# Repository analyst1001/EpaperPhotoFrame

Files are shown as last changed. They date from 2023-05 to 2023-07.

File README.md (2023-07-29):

# E-Paper Photo Frame

## Goals
- The main goal is to display photos on a E-paper display so that it looks similar to a photo frame. The displayed photo will change periodically.
- An additional goal is to allow the device to run on a common battery power source so that it can work without plugging into wall power.

## How to use
The script stored in `Software/transform_images.py` can be used to modify images in common format (png, jpg, etc.) to binary blobs which can be copied to a FAT32 partition (formatted with block size 512) on a SD card. These blobs are read by software starting with filename "0.bin", "1.bin", and so on and displayed on the E-paper screen. When a filename "<n>.bin" for some number `n` is not found, the software starts displaying images from "0.bin" again and keeps looping like this.

## Branches
This branch has PCB design to hold all the components for E-paper photo frame with connections to external battery, external E-paper display, external LEDs, and external SD card storage. Additionally it has code that can be flashed to STM32 MCU to use the PCB as an Epaper photo frame.
The branch `development_board` has code to run software on the development board with appropriate connections to external devices.

## MCU interfaces
- SPI interface is used to communicate with SD card and E-paper display.
- UART interface is used to log debug messages. This can be disabled by a C macro to reduce power usage in the final version.
- GPIOs to power on/off BUSY and ERROR LEDs, and SD card.

## Code implementation
1. Initialize the MCU using HAL layer. Configure system clock to use 80MHz. Using the max frequency allows SPI interface to SD card to communicate with max speed. This will allow SD card to be powered on for a shorter amount of time hence reducing the power usage (given that I plan to keep the MCU in low power mode for hours).
2. Initialize LEDs and RTC peripheral. BUSY LED indicates that the MCU is busy using the SD card or the E-paper display. ERROR LED indicates that an irrecoverable error has occurred. RTC peripheral is used to leverage the WakeUp timer in order to wake up the MCU from sleep mode periodically.
3. Initialize SD card and E-paper display.
4. Read data from the file to display and send it to E-paper display. Refresh the display and put it to sleep when the image is displayed.
5. Enable WakeUp interrupt to wake up the processor after given time interval.
6. Configure peripherals to reduce current consumption and put the MCU in Standby/Shutdown mode.

## Current consumption (TBD)

## Future Plans
- Use a data logger to measure instantaneous current consumption value with better resolution.
- Re-write the logic to use interrupt based processing. The SPI based communication can use interrupt based processing where the MCU can be put into low-power sleep mode when waiting for data transmission/reception. Same can be used when waiting for BUSY signal from E-paper display and time delays in the logic.
- Use DMA peripheral to transmit/receive large data blobs (image pixel data). STM32L4 series processor support a feature called Batch Acquisition sub-mode(BAM), as mentioned in Section 2.1.1 of [AN4621](https://www.st.com/resource/en/application_note/an4621-stm32l4-and-stm32l4-ultralowpower-features-overview-stmicroelectronics.pdf), that could allow this.

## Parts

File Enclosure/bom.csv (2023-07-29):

Item | Quantity | URL | Comments
Enclosure front cover | 1 | https://github.com/analyst1001/EpaperPhotoFrame/tree/main/Enclosure
Enclosure back cover | 1 | https://github.com/analyst1001/EpaperPhotoFrame/tree/main/Enclosure
Enclosure hanging attachment (optional) | 1 | https://github.com/analyst1001/EpaperPhotoFrame/tree/main/Enclosure
PCB | 1 | https://github.com/analyst1001/EpaperPhotoFrame/tree/main/PCB | BOM for PCB should be present in PCB directory
7.3inch ACeP 7-Color E-Paper E-Ink Display Module (800×480 Pixels) | 1 | https://www.waveshare.com/product/displays/e-paper/epaper-1/7.3inch-e-paper-f.htm | Buy one with
M3 x 0.5 mm screws | 4 | https://www.mcmaster.com/91280A039/
M3 x 0.5 mm nuts | 4 | https://www.mcmaster.com/90592A085/
LiPo battery (2000mAh) | 1 | https://mou.sr/4784RWG | Lower capacity battery should also be fine
LED Red | 1 |  | Any other color to represent error state can be used
LED Blue | 1 |  | Any other color to represent busy state can be used
Wires | 4 |  | To connect LEDs to PCB. Preferrably red for positive terminals and black for negative terminals
Double sided tape or Velcro tape | 1 |  | To attach battery to back cover
Glue | 1 |  | To attach screws to back cover

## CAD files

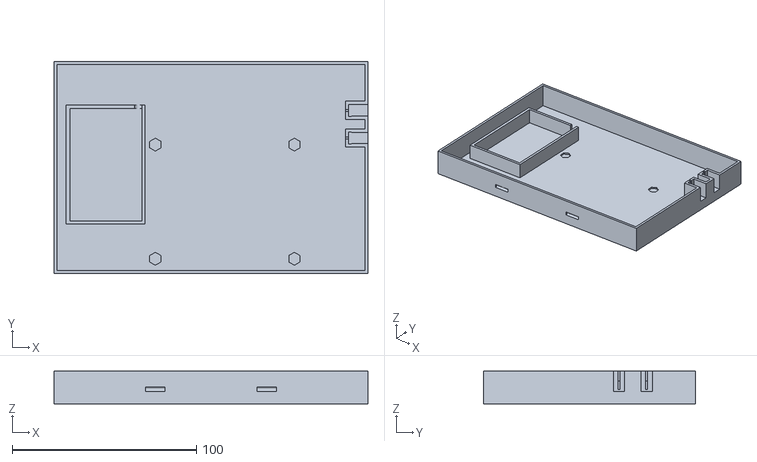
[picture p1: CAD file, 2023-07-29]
Enclosure/back_cover.stl
170.4 x 115.2 x 17.7

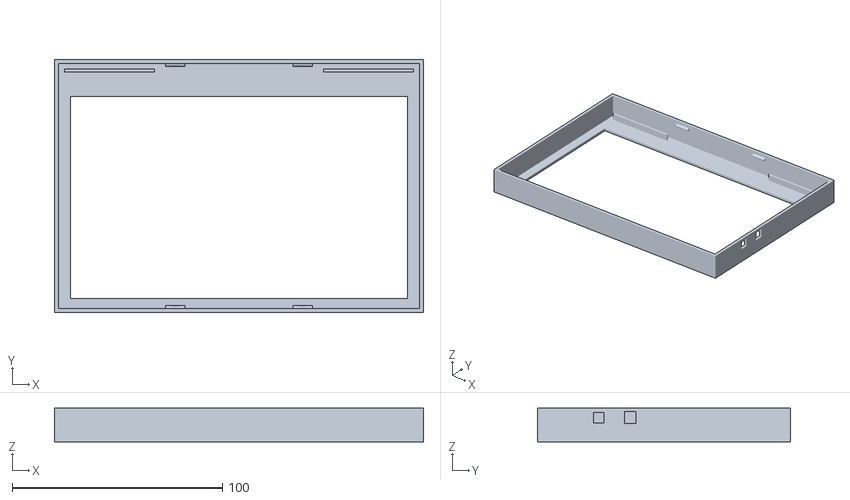
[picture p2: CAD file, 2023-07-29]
Enclosure/FrontCover_oriented.stl
175.4 x 120.2 x 16.0

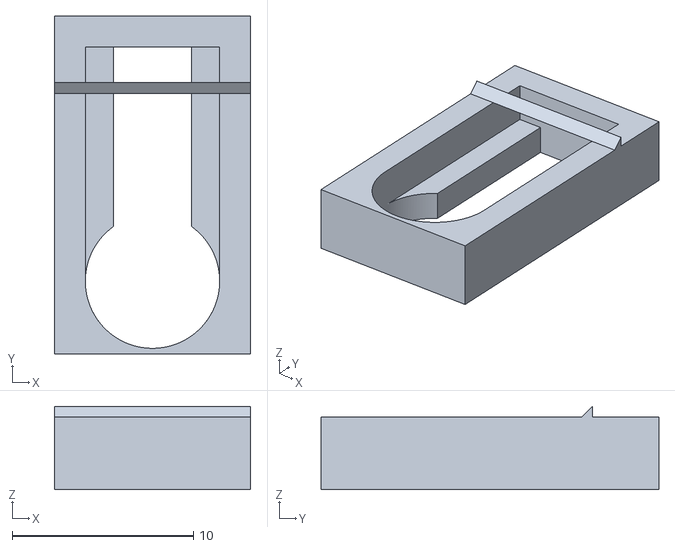
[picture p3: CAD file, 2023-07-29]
Enclosure/hanging_hook.stl
10.8 x 18.6 x 4.60

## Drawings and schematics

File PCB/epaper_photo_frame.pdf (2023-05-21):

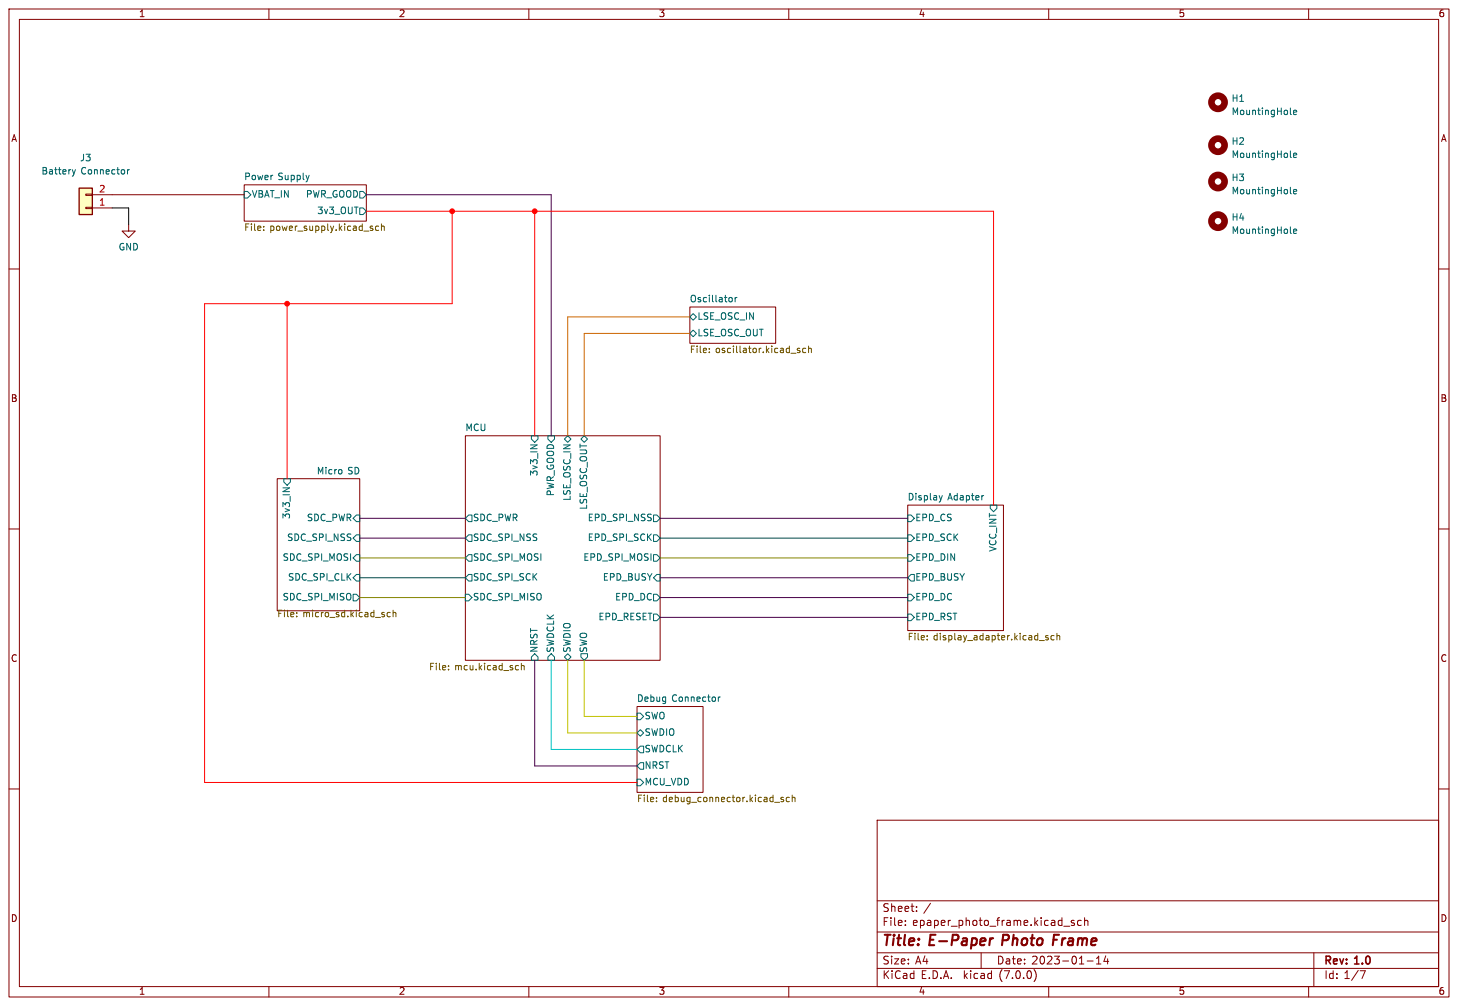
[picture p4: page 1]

LSE_OSC_OUT Oscillator File: oscillator.kicad_sch GND

SWO
SWDIO
File: epaper_photo_frame.kicad_sch Sheet: / NRST SWDCLK MCU_VDD

Id: 1/7 Title: E-Paper Photo Frame

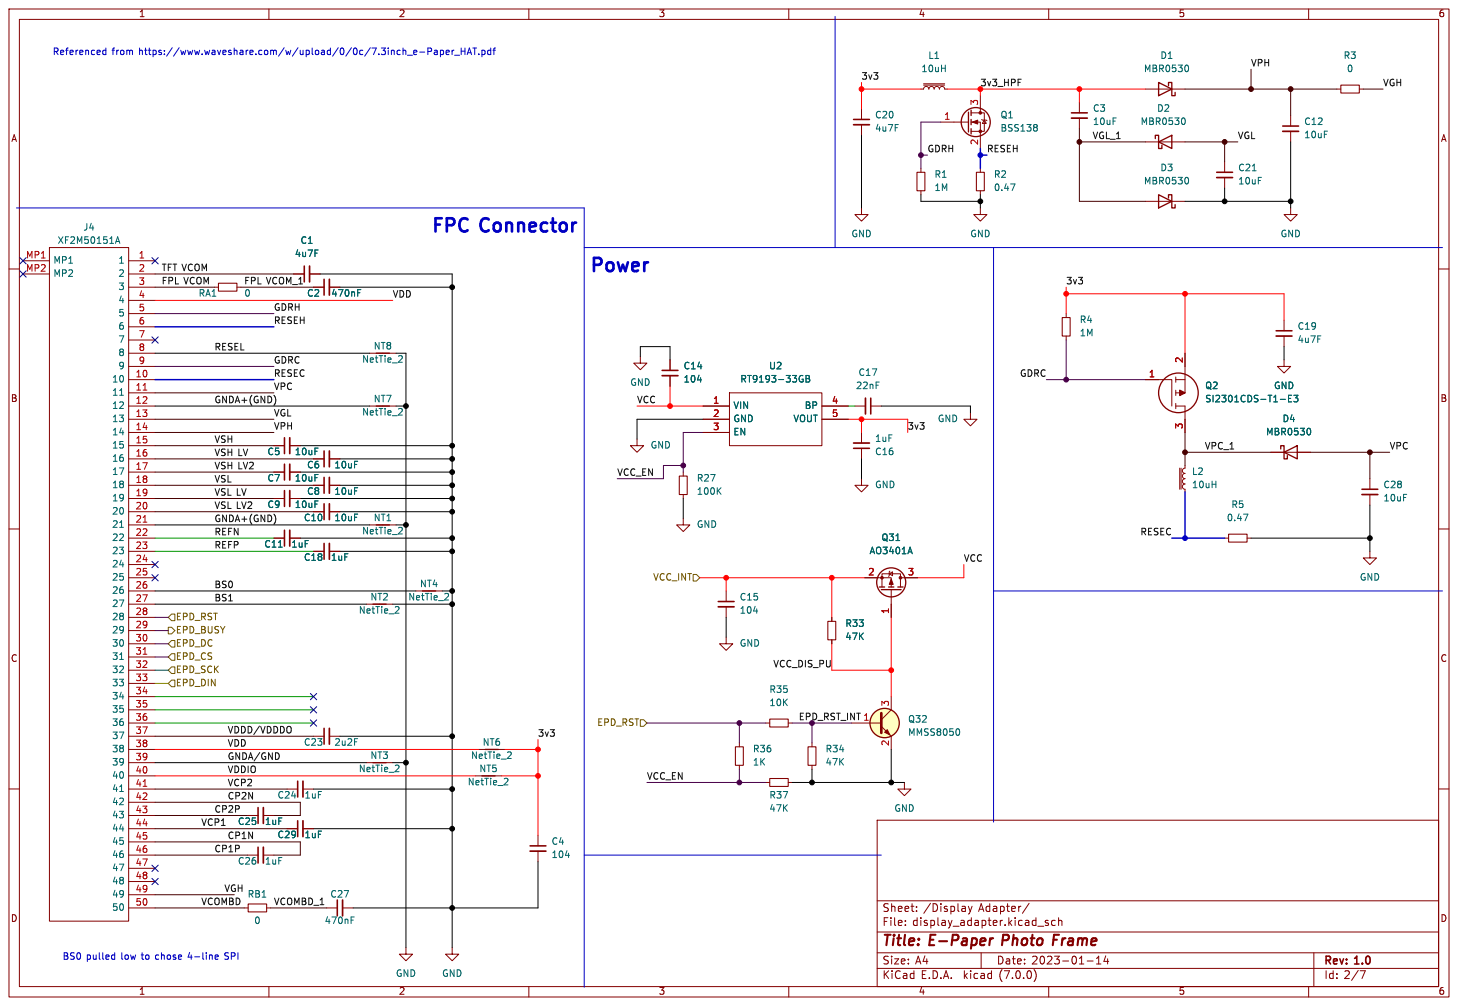
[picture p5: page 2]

Referenced from https://www.waveshare.com/w/upload/0/0c/7.3inch_e-Paper_HAT.pdf

Id: 2/7 Title: E-Paper Photo Frame

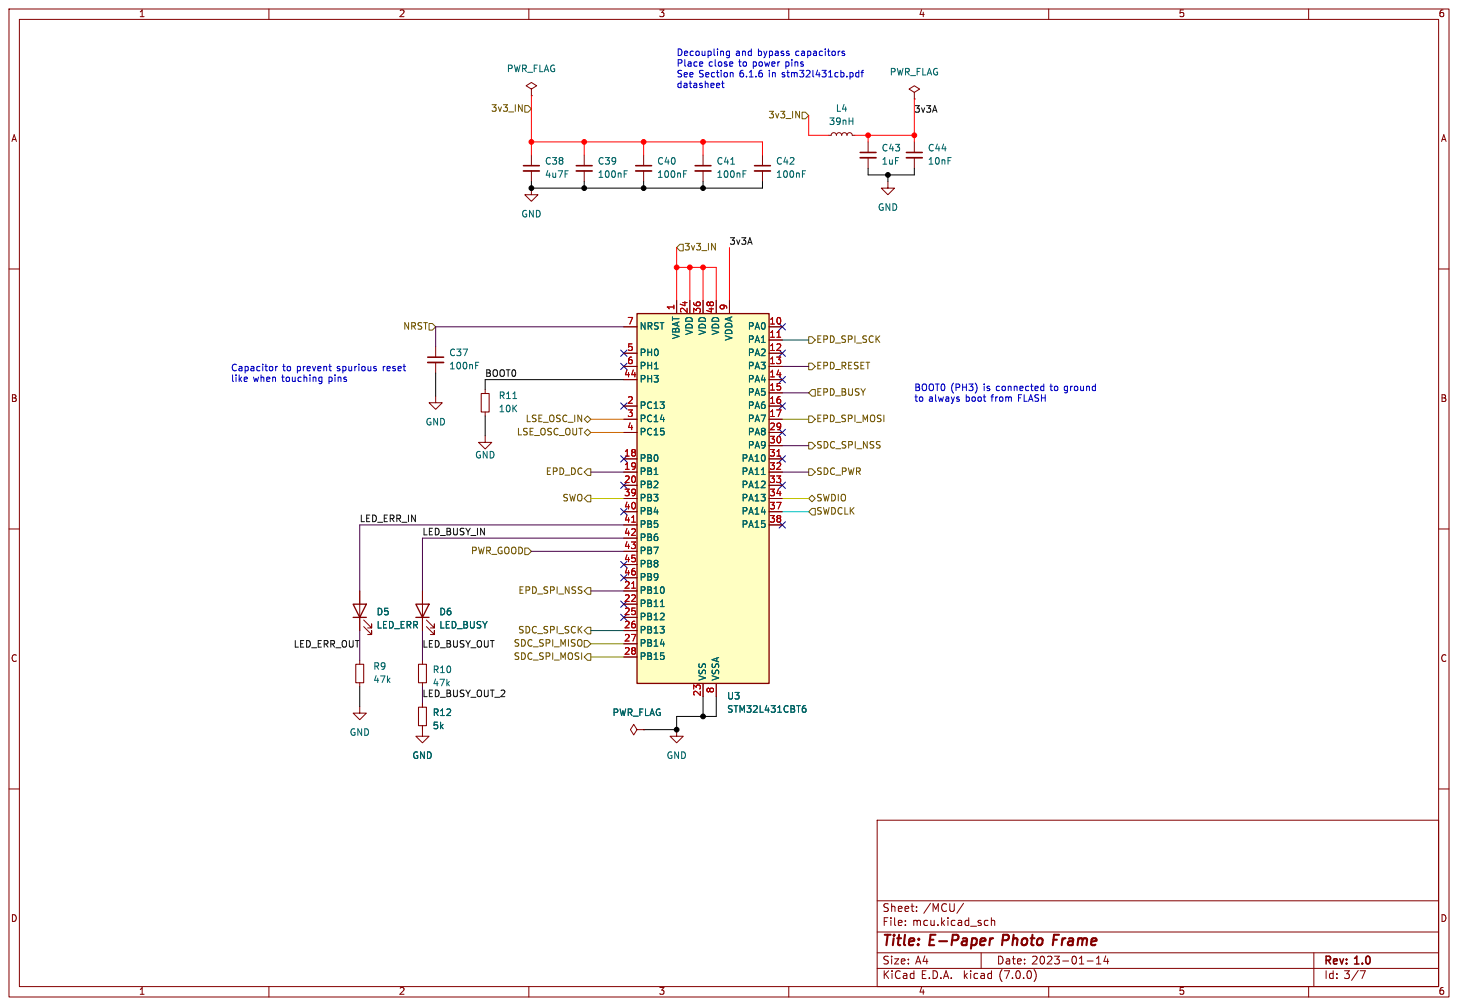
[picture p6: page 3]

1 PA0 10 PA1 11 PA2 12 PA3 13 PA4 14 PA5 15 PA6 16 PA7 17 PB0 18 PB1 19 PC13 2 PB2 20 PB10 21 PB11 22 VSS 23 VDD 24 PB12 25 PB13 26 PB14 27 PB15 28 PA8 29 PC14 3 PA9 30 PA10 31 PA11 32 PA12 33 PA13 34 VDD 36 PA14 37 PA15 38 PB3 39 PC15 4 PB4 40 PB5 41 PB6 42 PB7 43 PH3 44 PB8 45 PB9 46 VDD 48 PH0 5 PH1 6 NRST 7 VSSA
LSE_OSC_OUT EPD_SPI_NSS

Capacitor to prevent spurious reset

to always boot from FLASH

Id: 3/7 Title: E-Paper Photo Frame

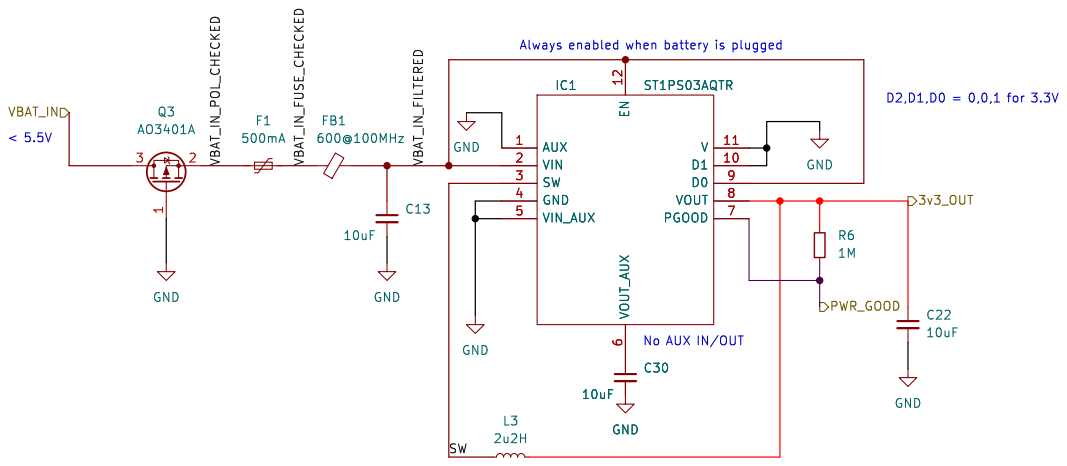
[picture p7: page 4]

File: power_supply.kicad_sch Sheet: /Power Supply/ R6

Id: 4/7 Title: E-Paper Photo Frame

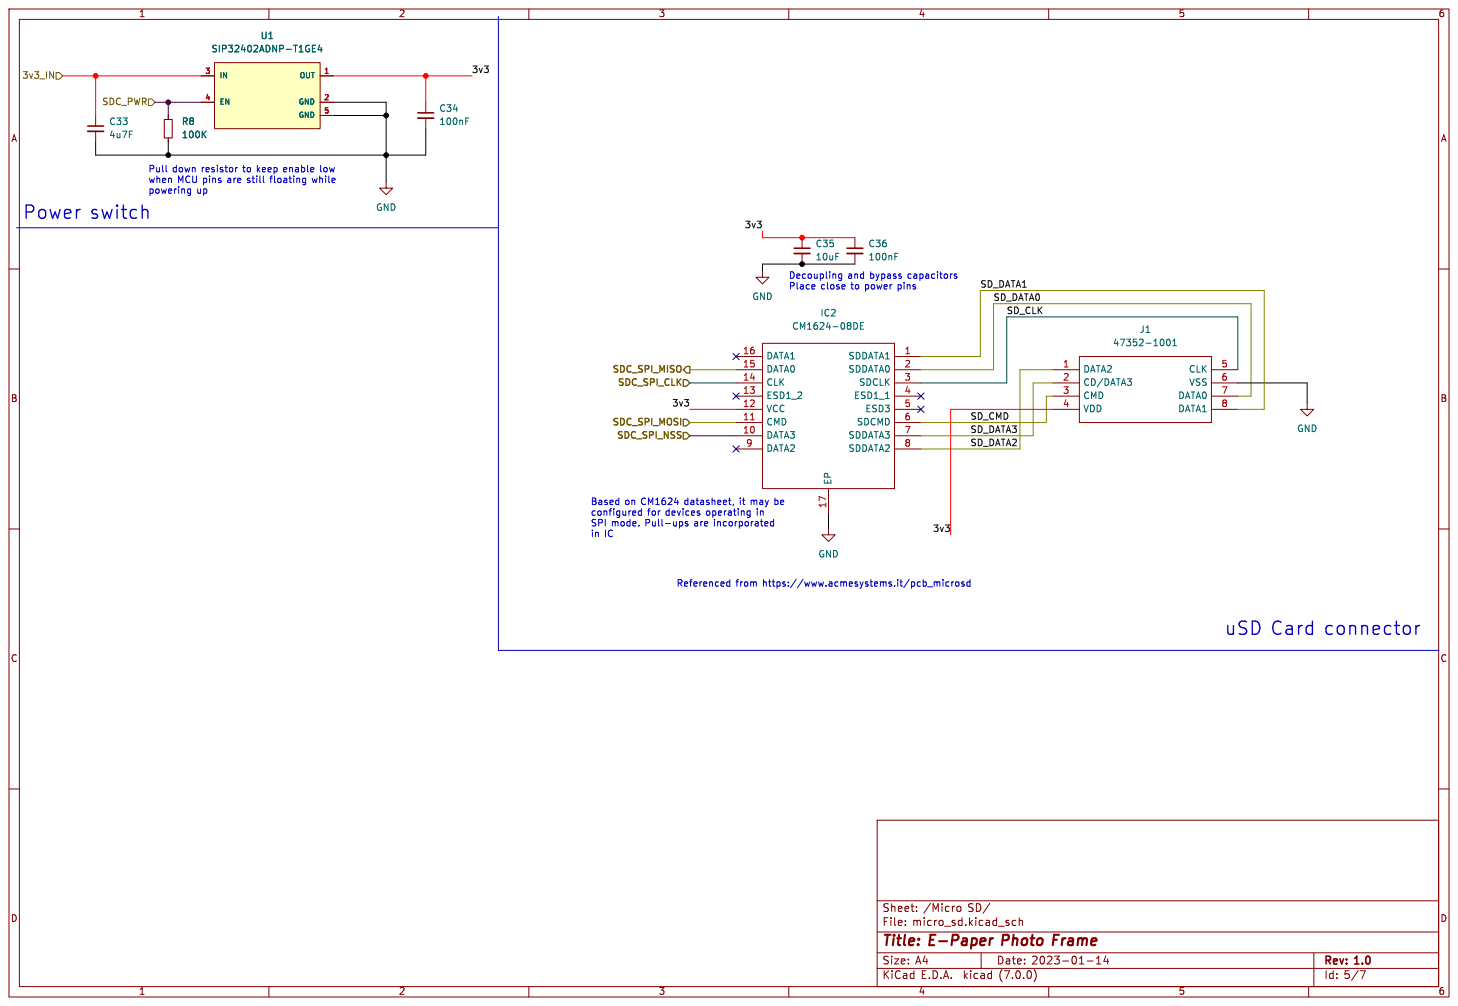
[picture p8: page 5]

Pull down resistor to keep enable low

Referenced from https://www.acmesystems.it/pcb_microsd

File: micro_sd.kicad_sch Sheet: /Micro SD/
Id: 5/7 Title: E-Paper Photo Frame

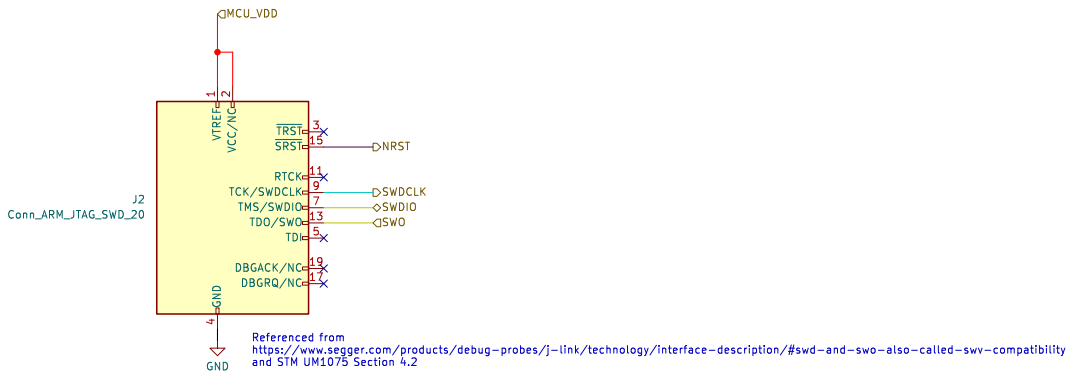
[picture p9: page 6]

1 RTCK 11 TDO/SWO 13 ~{SRST}15 DBGRQ/NC 17 DBGACK/NC 19 VCC/NC
Id: 6/7 Title: File: debug_connector.kicad_sch Sheet: /Debug Connector/ VTREF

SWDCLK NRST Referenced from

4 TDI 5 TMS/SWDIO 7 TCK/SWDCLK 9

https://www.segger.com/products/debug-probes/j-link/technology/interface-description/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 and STM UM1075 Section 4.2

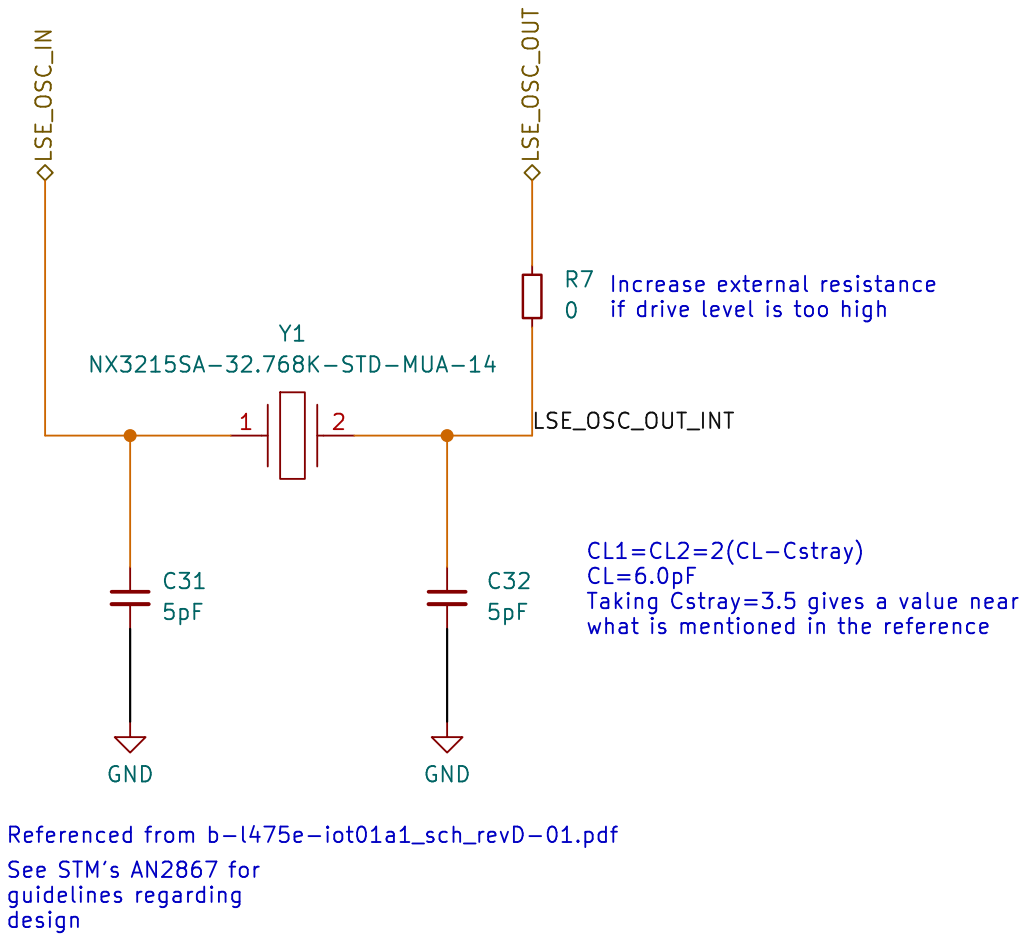
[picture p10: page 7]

Increase external resistance
if drive level is too high

Id: 7/7 Title: File: oscillator.kicad_sch Sheet: /Oscillator/

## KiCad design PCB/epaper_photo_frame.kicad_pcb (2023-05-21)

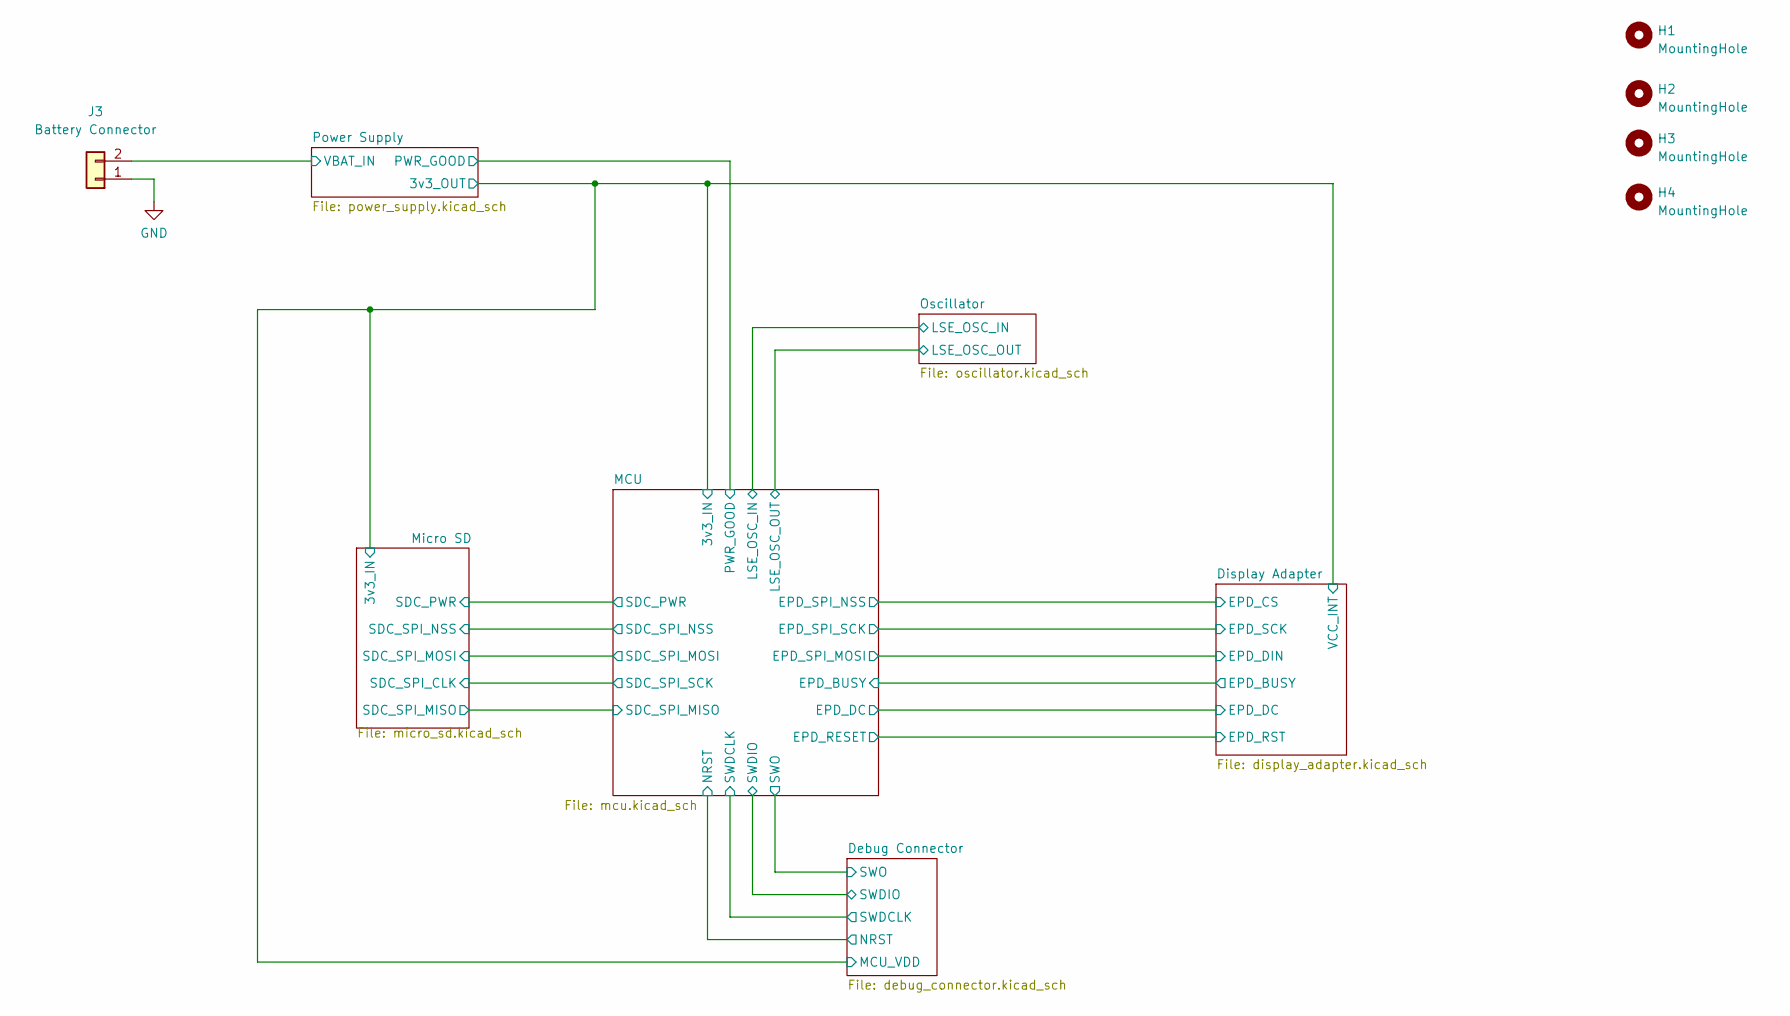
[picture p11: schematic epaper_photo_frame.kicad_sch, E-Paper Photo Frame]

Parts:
H1, H2, H3, H4: MountingHole; MountingHole_3.2mm_M3
J3: Battery Connector; JST_PH_B2B-PH-K_1x02_P2.00mm_Vertical

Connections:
/Power Supply/VBAT_IN: J3.2; also elsewhere on the board
GND: J3.1; also elsewhere on the board

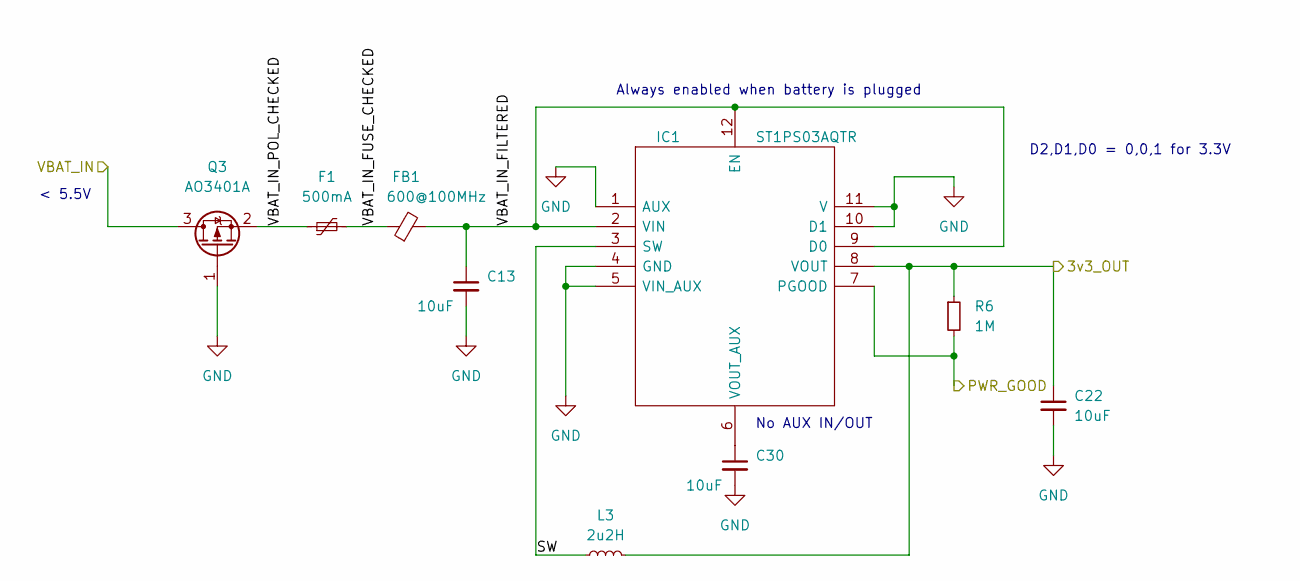
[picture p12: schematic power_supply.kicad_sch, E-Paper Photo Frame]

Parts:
C13, C22: 10uF; C_0805_2012Metric; LCSC C15850
C30: 10uF; C_0603_1608Metric; LCSC C96446
F1: 500mA; Fuse_1206_3216Metric; LCSC C69688
FB1: 600@100MHz; L_0805_2012Metric; LCSC C1017
IC1: ST1PS03AQTR; QFN40P170X200X55-12N-D; Manufacturer_Part_Number ST1PS03AQTR; Mouser Part Number 511-ST1PS03AQTR
L3: 2u2H; L_0805_2012Metric; LCSC C370034
Q3: AO3401A; SOT-23; LCSC C15127
R6: 1M; R_0805_2012Metric; LCSC C441966

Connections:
/Debug Connector/MCU_VDD: C22.1, IC1.8 (VOUT), L3.2, R6.1; also elsewhere on the board
/MCU/PWR_GOOD: IC1.7 (PGOOD), R6.2; also elsewhere on the board
/Power Supply/SW: IC1.3 (SW), L3.1
/Power Supply/VBAT_IN: Q3.3 (D); also elsewhere on the board
/Power Supply/VBAT_IN_FILTERED: C13.1, FB1.2, IC1.2 (VIN), IC1.9 (D0), IC1.12 (EN)
/Power Supply/VBAT_IN_FUSE_CHECKED: F1.2, FB1.1
/Power Supply/VBAT_IN_POL_CHECKED: F1.1, Q3.2 (S)
GND: C13.2, C22.2, C30.2, IC1.1 (AUX), IC1.4 (GND), IC1.5 (VIN_AUX), IC1.10 (D1), IC1.11 (V), Q3.1 (G); also elsewhere on the board
unnamed: C30.1, IC1.6 (VOUT_AUX)

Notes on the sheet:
D2,D1,D0 = 0,0,1 for 3.3V
No AUX IN/OUT
< 5.5V
Always enabled when battery is plugged

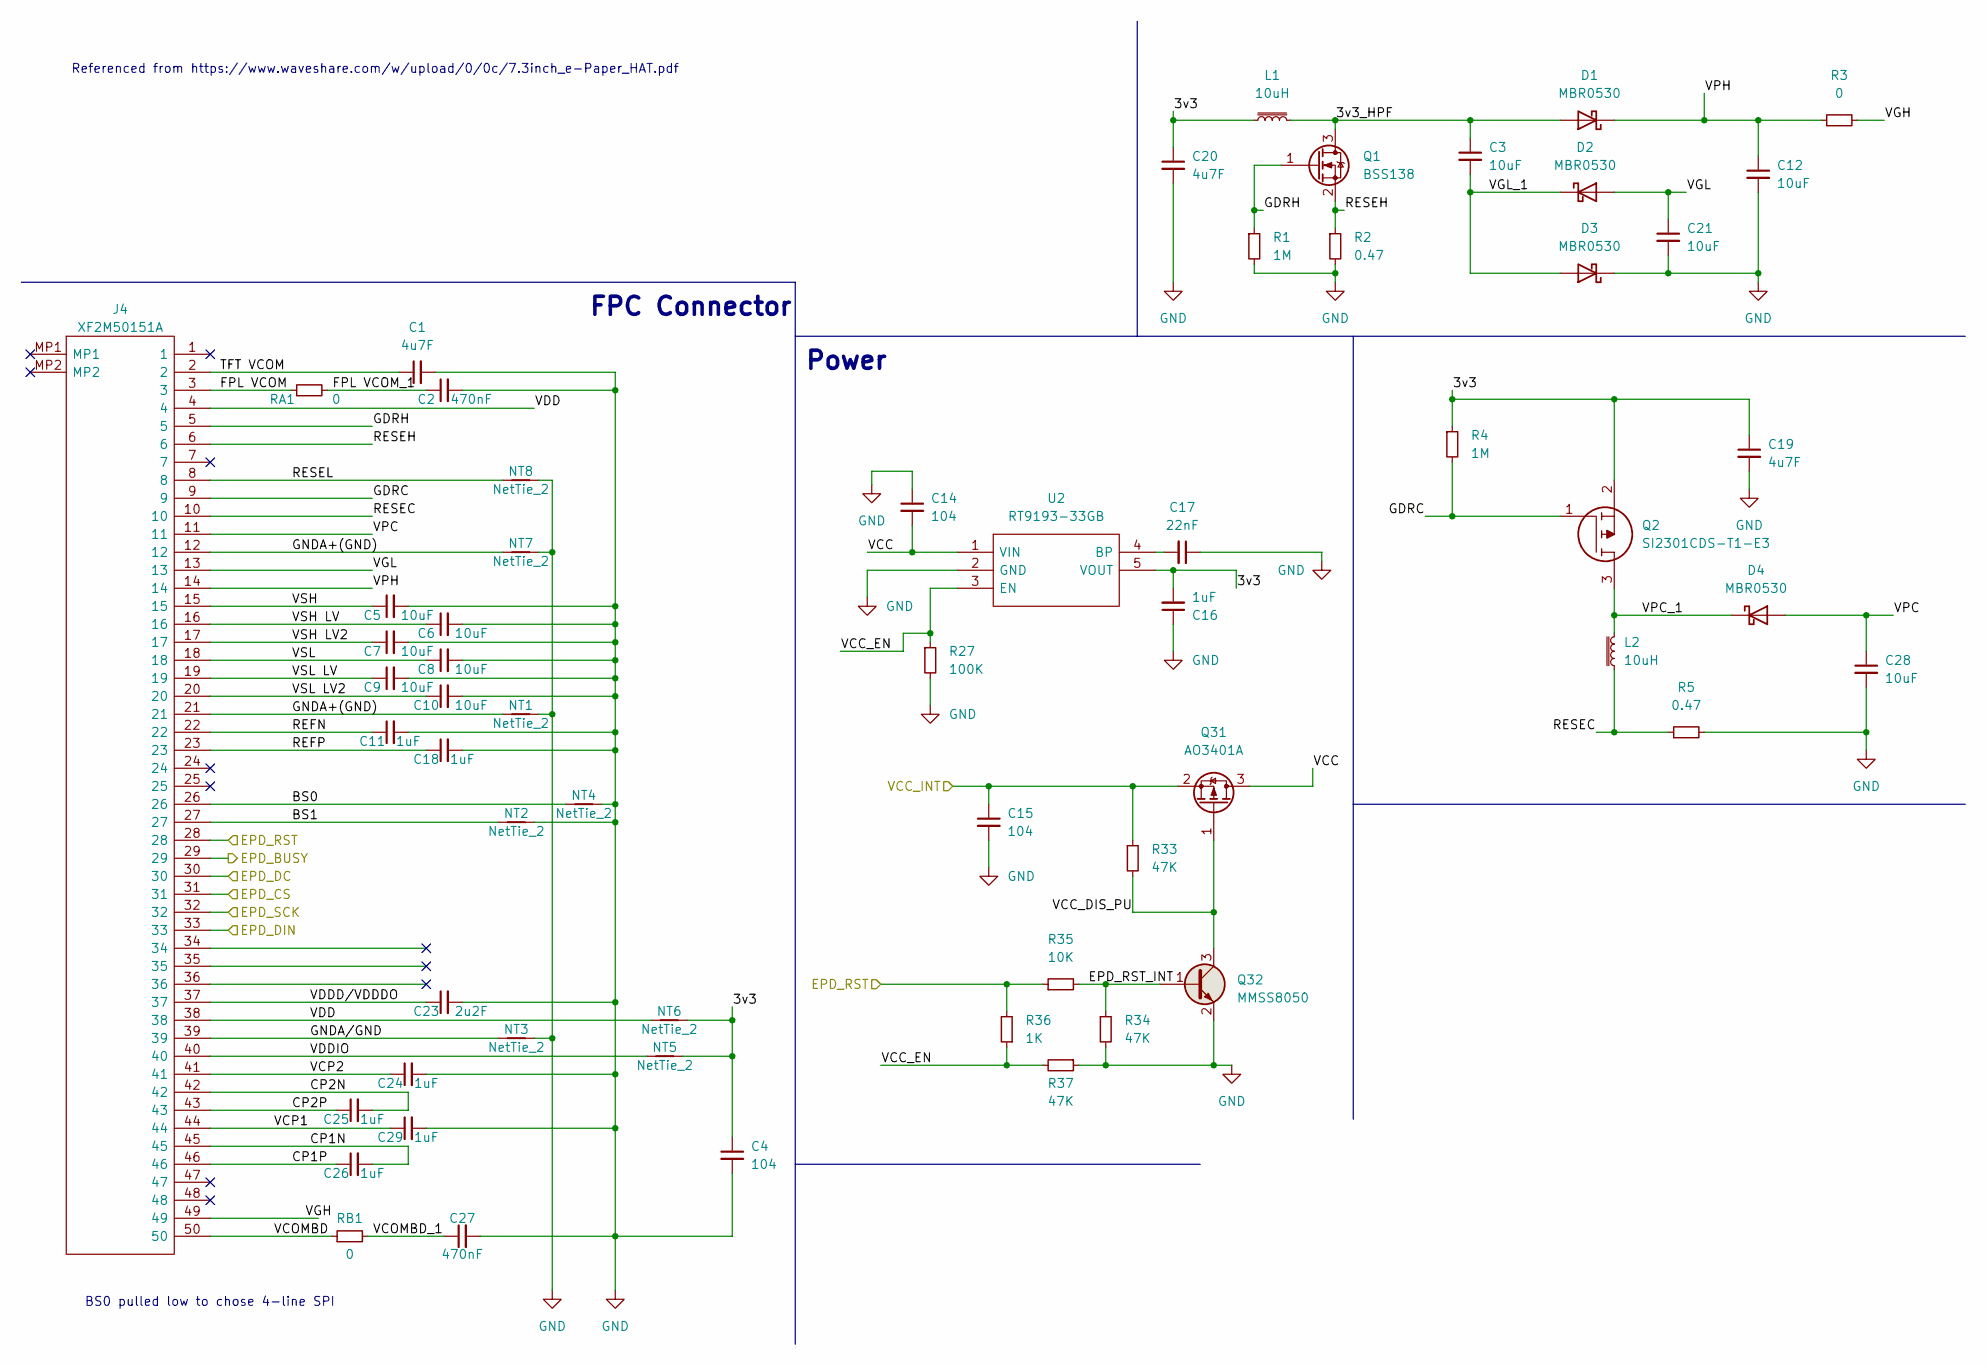
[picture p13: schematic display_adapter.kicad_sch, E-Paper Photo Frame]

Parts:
C1, C19, C20: 4u7F; C_0603_1608Metric; MAX Voltage 10V; LCSC C19666
C2, C27: 470nF; C_0603_1608Metric; MAX Voltage 25V; LCSC C1623
C3, C5, C6, C7, C8, C9, C10, C12, C21, C28: 10uF; C_0603_1608Metric; MAX Voltage 25V; LCSC C96446
C4: 104; C_0603_1608Metric; LCSC C14663
C11, C18, C24, C25, C26, C29: 1uF; C_0603_1608Metric; MAX Voltage 10V; LCSC C15849
C14, C15: 104; C_0805_2012Metric; LCSC C49678
C16: 1uF; C_0805_2012Metric; LCSC C28323
C17: 22nF; C_0805_2012Metric; LCSC C1729
C23: 2u2F; C_0603_1608Metric; MAX Voltage 6V; LCSC C23630
D1, D2, D3, D4: MBR0530; D_SOD-123; LCSC C18863
J4: XF2M50151A; Manufacturer_Part_Number XF2M50151A; LCSC C188356
L1, L2: 10uH; INDPM4040X200N; LCSC C82398
NT1, NT2, NT3, NT4, NT5, NT6, NT7, NT8: NetTie_2; NetTie-2_SMD_Pad0.5mm
Q1: BSS138; SOT-23; LCSC C82045
Q2: SI2301CDS-T1-E3; SOT95P237X112-3N; Manufacturer_Part_Number SI2301CDS-T1-E3; Mouser Part Number 781-SI2301CDS-E3
Q31: AO3401A; SOT-23; LCSC C15127
Q32: MMSS8050; SOT-23; LCSC C2150
R1, R4: 1M; R_0805_2012Metric; LCSC C441966
R2, R5: 0.47; R_0805_2012Metric; LCSC C491238
R3: 0; R_0805_2012Metric; LCSC C17477
R27: 100K; R_0805_2012Metric; LCSC C149504
R33, R34, R37: 47K; R_0805_2012Metric; LCSC C17713
R35: 10K; R_0805_2012Metric; LCSC C510098
R36: 1K; R_0805_2012Metric; LCSC C17513
RA1: 0; R_0805_2012Metric; LCSC C17477
RB1: 0; R_0805_2012Metric; LCSC C17477
U2: RT9193-33GB; SOT94P279X130-5N; Manufacturer_Part_Number RT9193-33GB; LCSC C15651

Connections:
/Debug Connector/MCU_VDD: C15.1, Q31.2 (S), R33.1; also elsewhere on the board
/Display Adapter/3v3: C4.1, C16.2, C19.1, C20.1, L1.1, NT5.2, NT6.2, Q2.2, R4.1, U2.5 (VOUT)
/Display Adapter/3v3_HPF: C3.1, D1.2 (A), L1.2, Q1.3 (D)
/Display Adapter/BS0: J4.26, NT4.1
/Display Adapter/BS1: J4.27, NT2.1
/Display Adapter/CP1N: C26.2, J4.45
/Display Adapter/CP1P: C26.1, J4.46
/Display Adapter/CP2N: C25.2, J4.42
/Display Adapter/CP2P: C25.1, J4.43
/Display Adapter/EPD_BUSY: J4.29; also elsewhere on the board
/Display Adapter/EPD_CS: J4.31; also elsewhere on the board
/Display Adapter/EPD_DC: J4.30; also elsewhere on the board
/Display Adapter/EPD_DIN: J4.33; also elsewhere on the board
/Display Adapter/EPD_RST: J4.28, R35.1, R36.2; also elsewhere on the board
/Display Adapter/EPD_RST_INT: Q32.1 (B), R34.1, R35.2
/Display Adapter/EPD_SCK: J4.32; also elsewhere on the board
/Display Adapter/FPL VCOM: J4.3, RA1.1
/Display Adapter/FPL VCOM_1: C2.1, RA1.2
/Display Adapter/GDRC: J4.9, Q2.1, R4.2
/Display Adapter/GDRH: J4.5, Q1.1 (G), R1.1
/Display Adapter/GNDA+(GND): J4.12, J4.21, NT1.1, NT7.1
/Display Adapter/GNDA/GND: J4.39, NT3.1
/Display Adapter/REFN: C11.1, J4.22
/Display Adapter/REFP: C18.1, J4.23
/Display Adapter/RESEC: J4.10, L2.1, R5.1
/Display Adapter/RESEH: J4.6, Q1.2 (S), R2.1
/Display Adapter/RESEL: J4.8, NT8.1
/Display Adapter/TFT VCOM: C1.1, J4.2
/Display Adapter/VCC: C14.2, Q31.3 (D), U2.1 (VIN)
/Display Adapter/VCC_DIS_PU: Q31.1 (G), Q32.3 (C), R33.2
/Display Adapter/VCC_EN: R27.1, R36.1, R37.2, U2.3 (EN)
/Display Adapter/VCOMBD: J4.50, RB1.1
/Display Adapter/VCOMBD_1: C27.1, RB1.2
/Display Adapter/VCP1: C29.1, J4.44
/Display Adapter/VCP2: C24.1, J4.41
/Display Adapter/VDD: J4.4, J4.38, NT6.1
/Display Adapter/VDDD/VDDDO: C23.1, J4.37
/Display Adapter/VDDIO: J4.40, NT5.1
/Display Adapter/VGH: J4.49, R3.2
/Display Adapter/VGL: C21.1, D2.2 (A), J4.13
/Display Adapter/VGL_1: C3.2, D2.1 (K), D3.2 (A)
/Display Adapter/VPC: C28.1, D4.2 (A), J4.11
/Display Adapter/VPC_1: D4.1 (K), L2.2, Q2.3
/Display Adapter/VPH: C12.1, D1.1 (K), J4.14, R3.1
/Display Adapter/VSH: C5.1, J4.15
/Display Adapter/VSH LV: C6.1, J4.16
/Display Adapter/VSH LV2: C7.1, J4.17
/Display Adapter/VSL: C8.1, J4.18
/Display Adapter/VSL LV: C9.1, J4.19
/Display Adapter/VSL LV2: C10.1, J4.20
GND: C1.2, C2.2, C4.2, C5.2, C6.2, C7.2, C8.2, C9.2, C10.2, C11.2, C12.2, C14.1, C15.2, C16.1, C17.1, C18.2, C19.2, C20.2, C21.2, C23.2, C24.2, C27.2, C28.2, C29.2, D3.1 (K), NT1.2, NT2.2, NT3.2, NT4.2, NT7.2, NT8.2, Q32.2 (E), R1.2, R2.2, R5.2, R27.2, R34.2, R37.1, U2.2 (GND); also elsewhere on the board
unnamed: C17.2, U2.4 (BP)

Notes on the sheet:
FPC Connector
BS0 pulled low to chose 4-line SPI
Power
Referenced from https://www.waveshare.com/w/upload/0/0c/7.3inch_e-Paper_HAT.pdf

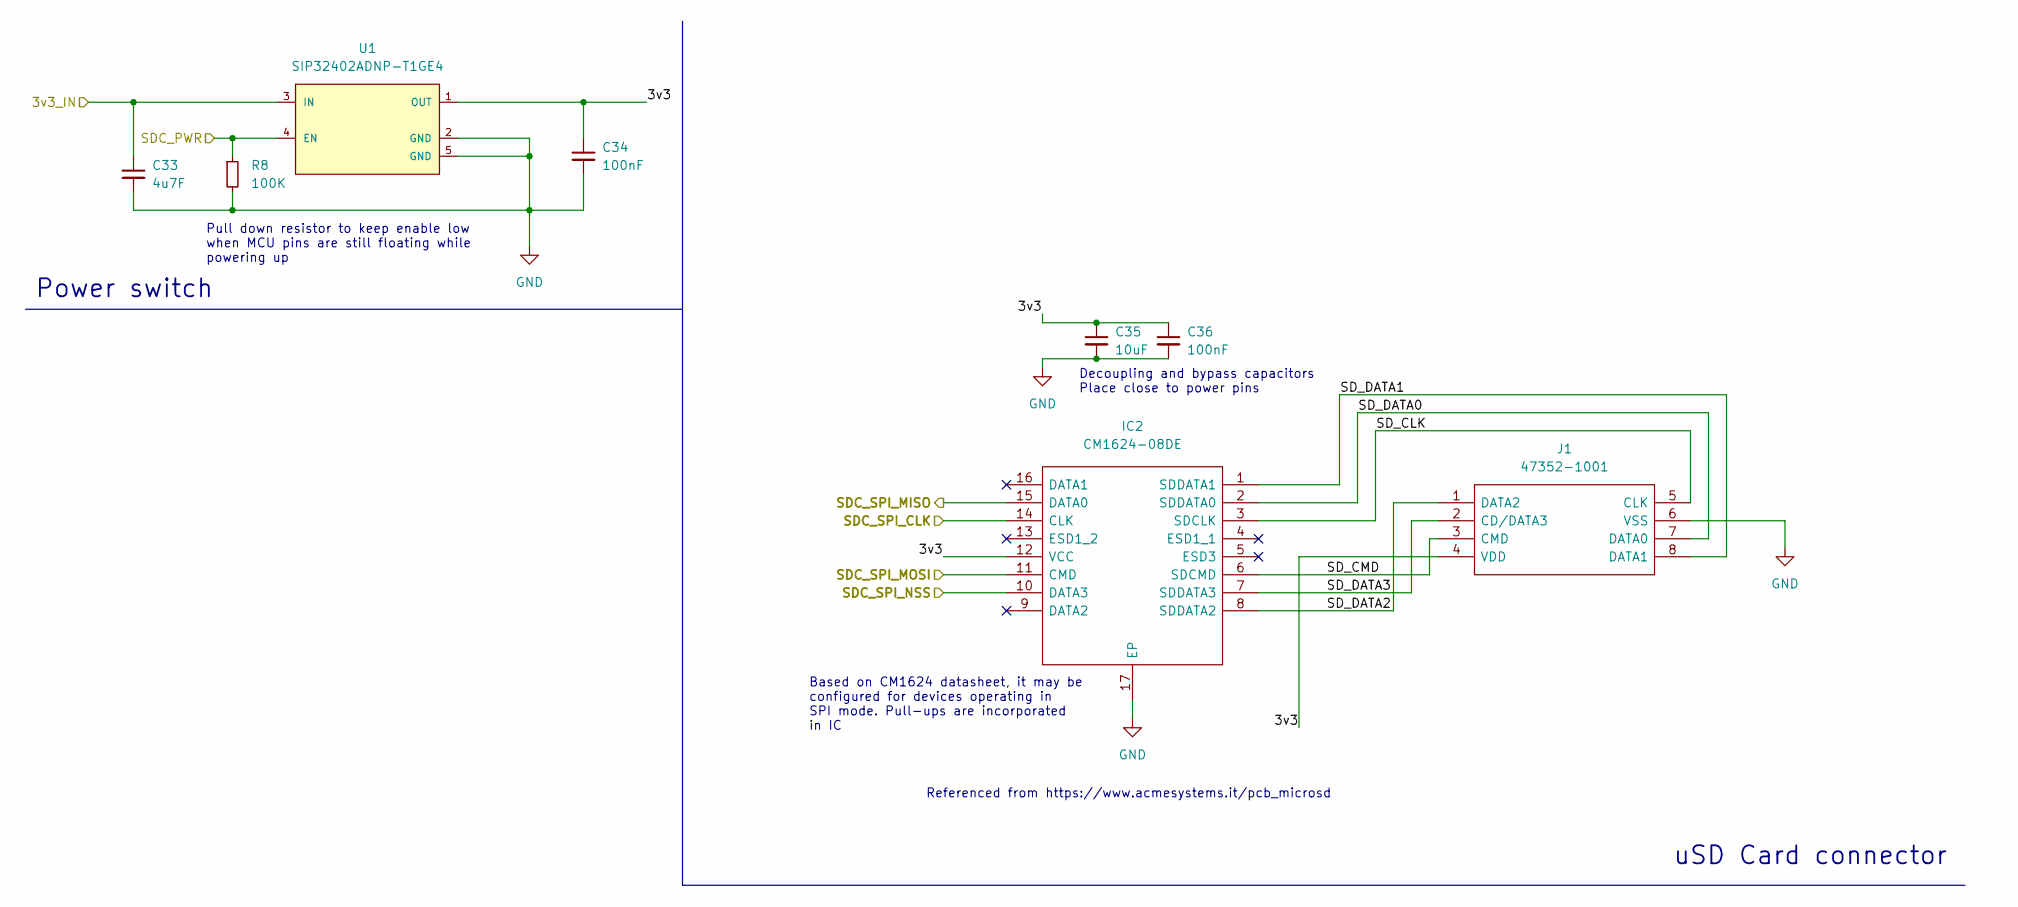
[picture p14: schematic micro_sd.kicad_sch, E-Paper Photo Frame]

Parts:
C33: 4u7F; C_0805_2012Metric; LCSC C1779
C34: 100nF; C_0805_2012Metric; LCSC C49678
C35: 10uF; C_0603_1608Metric; LCSC C96446
C36: 100nF; C_0603_1608Metric; LCSC C14663
IC2: CM1624-08DE; SON40P135X330X55-17N; Manufacturer_Part_Number CM1624-08DE; Mouser Part Number 748-CM1624-08DE
J1: 47352-1001; Manufacturer_Part_Number 47352-1001; Mouser Part Number 538-47352-1001
R8: 100K; R_0805_2012Metric; LCSC C149504
U1: SIP32402ADNP-T1GE4; Vishay-T16-0143-04_2016-C-MFG; mouser part number 78-SIP32402ADNPT1GE4; digikey description IC PWR SWITCH N-CHAN 1:1 4TDFN

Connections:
/Debug Connector/MCU_VDD: C33.1, U1.3 (IN); also elsewhere on the board
/MCU/SDC_PWR: R8.1, U1.4 (EN); also elsewhere on the board
/MCU/SDC_SPI_MISO: IC2.15 (DATA0); also elsewhere on the board
/MCU/SDC_SPI_MOSI: IC2.11 (CMD); also elsewhere on the board
/MCU/SDC_SPI_NSS: IC2.10 (DATA3); also elsewhere on the board
/MCU/SDC_SPI_SCK: IC2.14 (CLK); also elsewhere on the board
/Micro SD/3v3: C34.1, C35.1, C36.1, IC2.12 (VCC), J1.4 (VDD), U1.1 (OUT)
/Micro SD/SD_CLK: IC2.3 (SDCLK), J1.5 (CLK)
/Micro SD/SD_CMD: IC2.6 (SDCMD), J1.3 (CMD)
/Micro SD/SD_DATA0: IC2.2 (SDDATA0), J1.7 (DATA0)
/Micro SD/SD_DATA1: IC2.1 (SDDATA1), J1.8 (DATA1)
/Micro SD/SD_DATA2: IC2.8 (SDDATA2), J1.1 (DATA2)
/Micro SD/SD_DATA3: IC2.7 (SDDATA3), J1.2 (CD/DATA3)
GND: C33.2, C34.2, C35.2, C36.2, IC2.17 (EP), J1.6 (VSS), R8.2, U1.2 (GND), U1.5 (GND); also elsewhere on the board

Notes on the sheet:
Referenced from https://www.acmesystems.it/pcb_microsd
Power switch
Pull down resistor to keep enable low when MCU pins are still floating while powering up
uSD Card connector
Decoupling and bypass capacitors Place close to power pins
Based on CM1624 datasheet, it may be configured for devices operating in SPI mode. Pull-ups are incorporated in IC

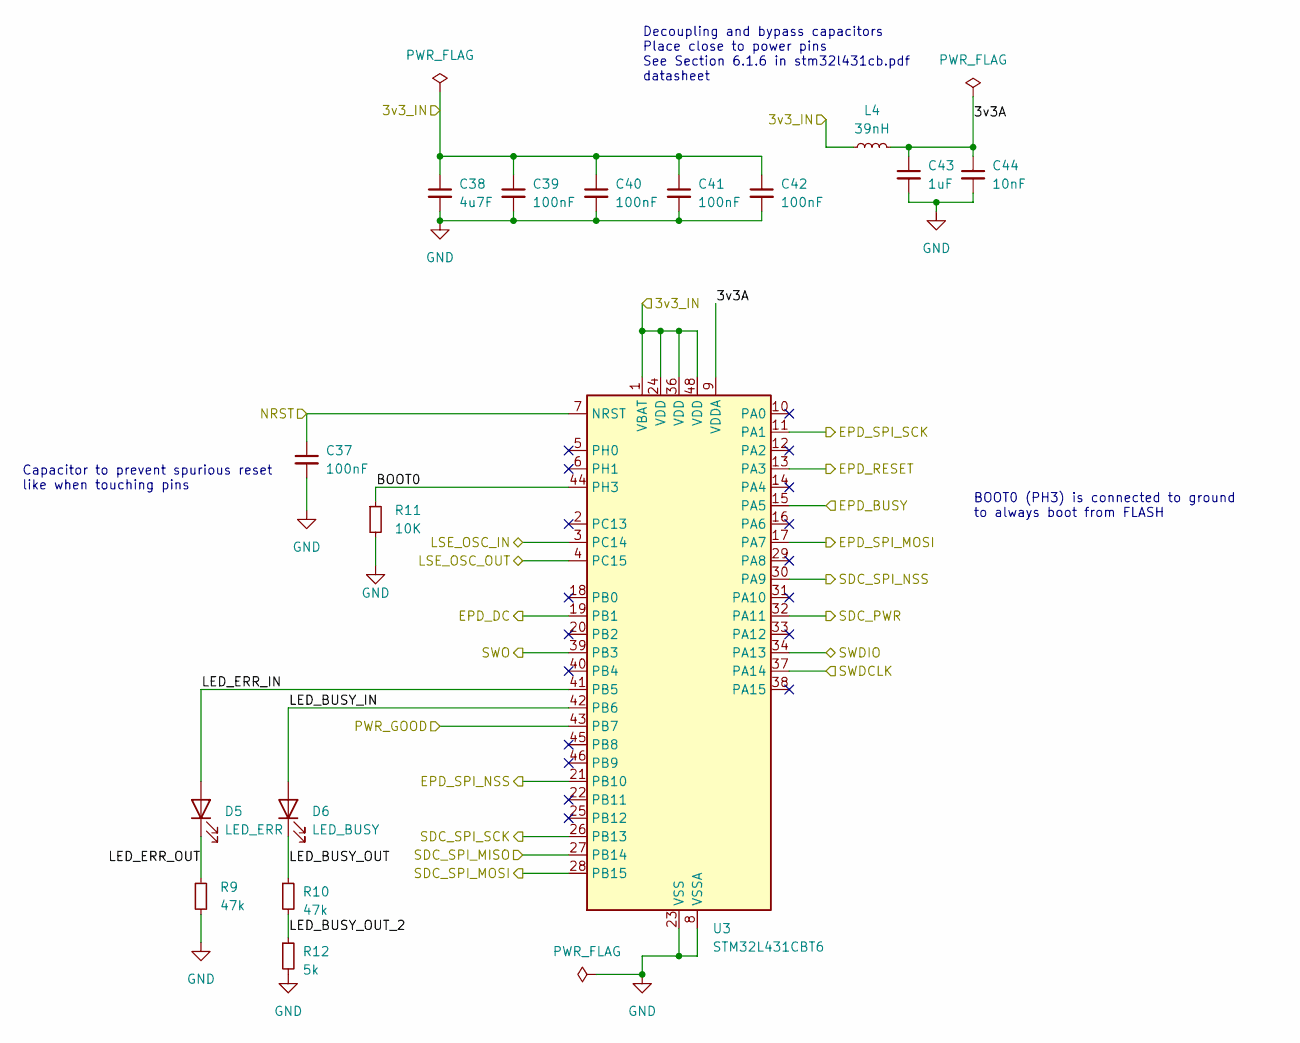
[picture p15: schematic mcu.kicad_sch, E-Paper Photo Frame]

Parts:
C37, C39, C40, C41, C42: 100nF; C_0603_1608Metric; LCSC C14663
C38: 4u7F; C_0603_1608Metric; LCSC C19666
C43: 1uF; C_0603_1608Metric; LCSC C15849
C44: 10nF; C_0603_1608Metric; LCSC C57112
D5: LED_ERR; LED_D3.0mm
D6: LED_BUSY; LED_D3.0mm
L4: 39nH; L_0402_1005Metric; LCSC C440213
R9, R10: 47k; R_1210_3225Metric; LCSC C230465
R11: 10K; R_0805_2012Metric; LCSC C510098
R12: 5k; R_1206_3216Metric; LCSC C870818
U3: STM32L431CBT6; LQFP-48_7x7mm_P0.5mm; LCSC C277951

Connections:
/Debug Connector/MCU_VDD: C38.1, C39.1, C40.1, C41.1, C42.1, L4.1, U3.1 (VBAT), U3.24 (VDD), U3.36 (VDD), U3.48 (VDD); also elsewhere on the board
/Debug Connector/NRST: C37.1, U3.7 (NRST); also elsewhere on the board
/Debug Connector/SWDCLK: U3.37 (PA14); also elsewhere on the board
/Debug Connector/SWDIO: U3.34 (PA13); also elsewhere on the board
/Debug Connector/SWO: U3.39 (PB3); also elsewhere on the board
/Display Adapter/EPD_BUSY: U3.15 (PA5); also elsewhere on the board
/Display Adapter/EPD_CS: U3.21 (PB10); also elsewhere on the board
/Display Adapter/EPD_DC: U3.19 (PB1); also elsewhere on the board
/Display Adapter/EPD_DIN: U3.17 (PA7); also elsewhere on the board
/Display Adapter/EPD_RST: U3.13 (PA3); also elsewhere on the board
/Display Adapter/EPD_SCK: U3.11 (PA1); also elsewhere on the board
/MCU/3v3A: C43.1, C44.1, L4.2, U3.9 (VDDA)
/MCU/BOOT0: R11.1, U3.44 (PH3)
/MCU/LED_BUSY_IN: D6.2 (A), U3.42 (PB6)
/MCU/LED_BUSY_OUT: D6.1 (K), R10.1
/MCU/LED_BUSY_OUT_2: R10.2, R12.1
/MCU/LED_ERR_IN: D5.2 (A), U3.41 (PB5)
/MCU/LED_ERR_OUT: D5.1 (K), R9.1
/MCU/LSE_OSC_IN: U3.3 (PC14); also elsewhere on the board
/MCU/LSE_OSC_OUT: U3.4 (PC15); also elsewhere on the board
/MCU/PWR_GOOD: U3.43 (PB7); also elsewhere on the board
/MCU/SDC_PWR: U3.32 (PA11); also elsewhere on the board
/MCU/SDC_SPI_MISO: U3.27 (PB14); also elsewhere on the board
/MCU/SDC_SPI_MOSI: U3.28 (PB15); also elsewhere on the board
/MCU/SDC_SPI_NSS: U3.30 (PA9); also elsewhere on the board
/MCU/SDC_SPI_SCK: U3.26 (PB13); also elsewhere on the board
GND: C37.2, C38.2, C39.2, C40.2, C41.2, C42.2, C43.2, C44.2, R9.2, R11.2, R12.2, U3.8 (VSSA), U3.23 (VSS), U3.35 (VSS), U3.47 (VSS); also elsewhere on the board

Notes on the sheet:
Capacitor to prevent spurious reset like when touching pins
BOOT0 (PH3) is connected to ground to always boot from FLASH
Decoupling and bypass capacitors Place close to power pins See Section 6.1.6 in stm32l431cb.pdf datasheet

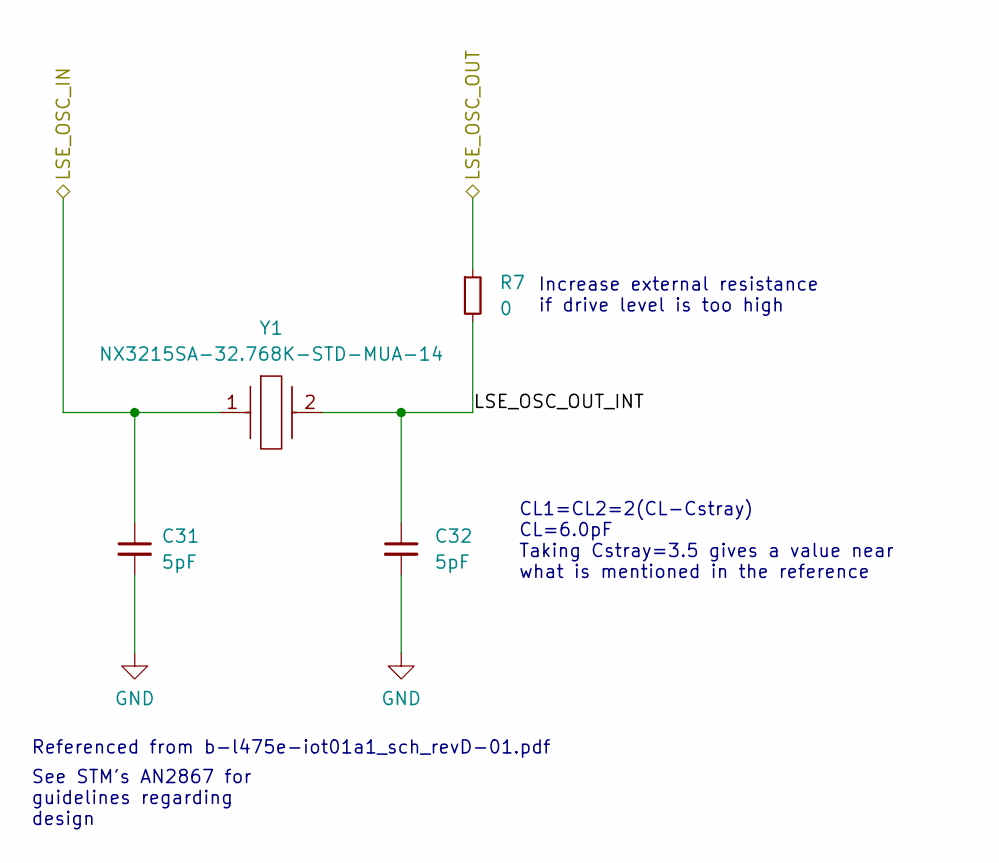
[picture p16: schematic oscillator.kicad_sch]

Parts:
C31, C32: 5pF; C_0402_1005Metric; LCSC C730435
R7: 0; R_0402_1005Metric; LCSC C17168
Y1: NX3215SA-32.768K-STD-MUA-14; NX3215SA32768KSTDMUA14; Manufacturer_Part_Number NX3215SA-32.768K-STD-MUA-14; Mouser Part Number 344-NX3215SA32768K14

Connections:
/MCU/LSE_OSC_IN: C31.1, Y1.1; also elsewhere on the board
/MCU/LSE_OSC_OUT: R7.1; also elsewhere on the board
/Oscillator/LSE_OSC_OUT_INT: C32.1, R7.2, Y1.2
GND: C31.2, C32.2; also elsewhere on the board

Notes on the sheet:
Referenced from b-l475e-iot01a1_sch_revD-01.pdf
See STM's AN2867 for guidelines regarding design
Increase external resistance if drive level is too high
CL1=CL2=2(CL-Cstray) CL=6.0pF Taking Cstray=3.5 gives a value near what is mentioned in the reference

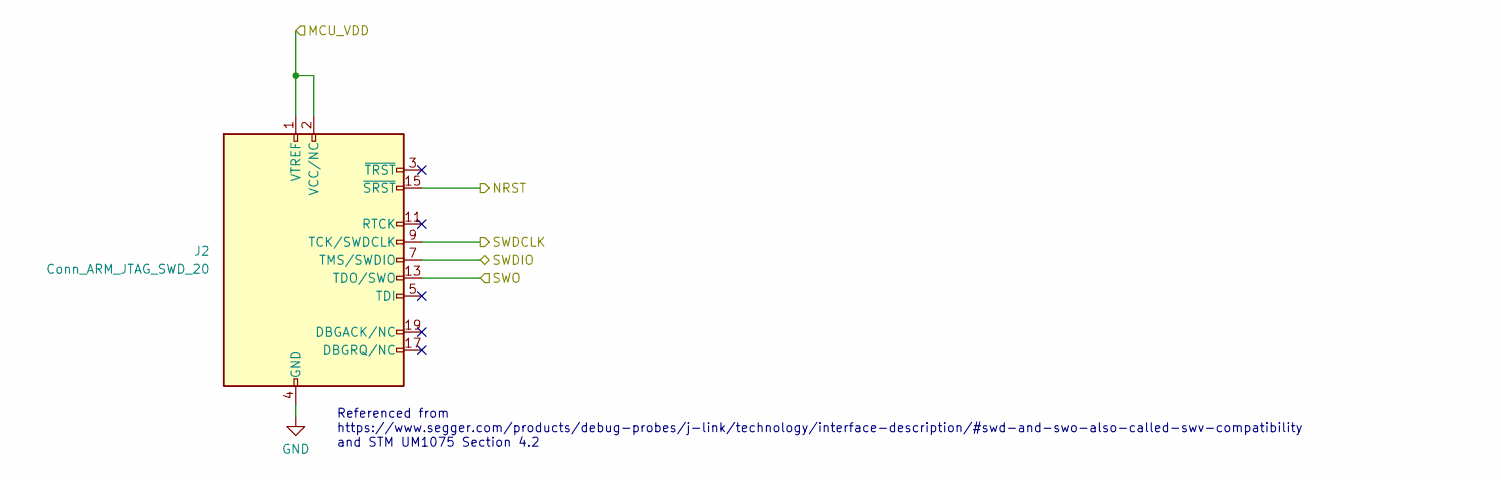
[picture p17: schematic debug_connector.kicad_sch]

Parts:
J2: Conn_ARM_JTAG_SWD_20; PinHeader_2x10_P2.54mm_Vertical

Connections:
/Debug Connector/MCU_VDD: J2.1 (VTREF), J2.2 (VCC/NC); also elsewhere on the board
/Debug Connector/NRST: J2.15 (~SRST); also elsewhere on the board
/Debug Connector/SWDCLK: J2.9 (TCK/SWDCLK); also elsewhere on the board
/Debug Connector/SWDIO: J2.7 (TMS/SWDIO); also elsewhere on the board
/Debug Connector/SWO: J2.13 (TDO/SWO); also elsewhere on the board
GND: J2.4 (GND), J2.6 (GND), J2.8 (GND), J2.10 (GND), J2.12 (GND), J2.14 (GND), J2.16 (GND), J2.18 (GND), J2.20 (GND); also elsewhere on the board

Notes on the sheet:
Referenced from https://www.segger.com/products/debug-probes/j-link/technology/interface-description/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 and STM UM1075 Section 4.2

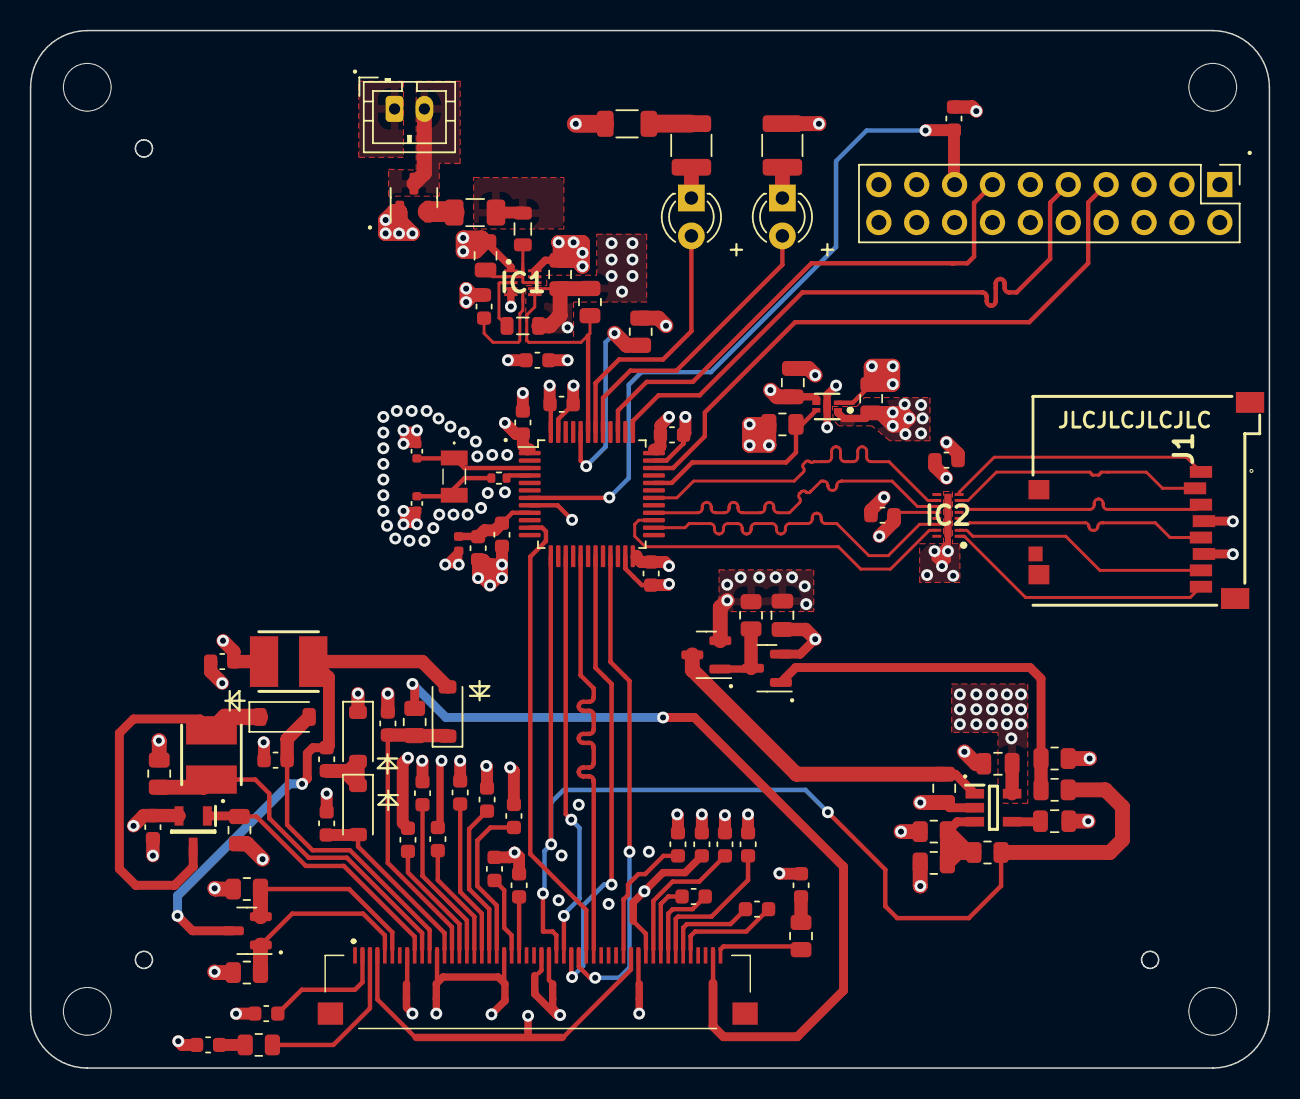
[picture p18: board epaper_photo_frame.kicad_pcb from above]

Board: 4 copper layers, 83.1 x 69.5 mm, 103 parts (0 on the bottom side), 85 nets.

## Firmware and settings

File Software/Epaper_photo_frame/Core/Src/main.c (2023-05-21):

#include <stdio.h>
#include <string.h>
#include "stm32l4xx_hal.h"
#include "main.h"
#include "epd.h"
#include "sdcard.h"
#include "fat32.h"
#include "led.h"
#include "rtc_and_pwr.h"
#include "logging.h"

static Boolean SystemClockConfig(void);
static void Early_Stage_Error_Handler(void);
static void Configure_For_Low_Power(void);

// Data buffer to store 1 cluster worth of data when reading file from SD card
// and processing it
static uint8_t data_buffer[SECTOR_SIZE * SECTORS_PER_CLUSTER];

static char filename_buffer[FILENAME_MAX_LENGTH];

int main(void) {
    Boolean is_bootup_from_lpm;
    uint32_t filename_counter;
    FAT32_Status fat32_ret;

    if (HAL_Init() != HAL_OK) {
        Early_Stage_Error_Handler();
    }

    Error_LED_Init();

    if (SystemClockConfig() != TRUE) {
        Error_Handler();
    }

    Logger_Init();

    Log_Msg("Log init success!!!\n");

    if (RTC_Init() != RTC_OK) {
        Log_Msg("Error initializing RTC peripheral");
        Error_Handler();
    }

    Busy_LED_Init();

    Log_Msg("Starting application!!");

    PWR_Handle_Boot_From_Low_Power_Mode(&is_bootup_from_lpm);

    if (is_bootup_from_lpm == TRUE) {
        Log_Msg("Booting up from low power mode");
        filename_counter = RTC_Read_Backup_Register(FILENAME_COUNTER_BKUP_REG);
    } else {
        filename_counter = 0;    // Start with filenames from 0.bin
    }

    snprintf(filename_buffer, FILENAME_MAX_LENGTH, "%lu.bin", filename_counter);

    // Light up the LED to indicate that the chip is starting main work
    Busy_LED_Indicate_Work_Start();

    if (EPD_Init() != EPD_OK) {
        Log_Msg("Error initializing E-paper display");
        Error_Handler();
    }
    Log_Msg("E-paper display initialized");

    if (EPD_Display_Clear(WHITE) != EPD_OK) {
        Log_Msg("Error clearing E-paper display screen");
        Error_Handler();
    }

    if (SDC_Init() != SDC_OK) {
        Log_Msg("Error initializing SD card");
        Error_Handler();
    }
    Log_Msg("SD card initialized!!");

    if (FAT32_Init() != FAT32_OK) {
        Log_Msg("Error initializing FAT32 module");
        Error_Handler();
    }
    Log_Msg("FAT32 initialized!!");

    fat32_ret = FAT32_Read_File_From_Root_Dir_And_Process_Data(filename_buffer,
            data_buffer, &EPD_Display_Image_Callback);
    if ((filename_counter > 0) && (fat32_ret == FAT32_READ_FILE_NOT_FOUND)) {
        // We ran out of all the files to display. Restart from 0.bin
        filename_counter = 0;
        snprintf(filename_buffer, FILENAME_MAX_LENGTH, "%lu.bin",
                filename_counter);
        fat32_ret = FAT32_Read_File_From_Root_Dir_And_Process_Data(
                filename_buffer, data_buffer, &EPD_Display_Image_Callback);
    }
    if (fat32_ret != FAT32_OK) {
        Log_Msg("Error reading file %s and displaying image!", filename_buffer);
        Error_Handler();
    }

    if (SDC_Power_Off() != SDC_OK) {
        Log_Msg("Error powering off SD card");
        Error_Handler();
    }

    HAL_Delay(2000);

    if (EPD_Put_To_Sleep() != EPD_OK) {
        Log_Msg("Error putting E-paper display to sleep");
        Error_Handler();
    }

    // Dim the LED to indicate that the chip has finished main work
    Busy_LED_Indicate_Work_End();

    if (EPD_De_Init() != EPD_OK) {
        Log_Msg("Error de-initializing E-paper display");
        Error_Handler();
    }

    Busy_LED_De_Init();

    // Increment the filename counter for reading the next file after exiting
    // sleep mode and store it in corresponding backup register
    RTC_Write_Backup_Register(FILENAME_COUNTER_BKUP_REG, filename_counter + 1);

    if (RTC_Set_WakeUp_Timer(SECONDS_TO_SPEND_IN_LOW_POWER_MODE) != RTC_OK) {
        Log_Msg("Could not set up RTC Wakeup timer for %d seconds",
        SECONDS_TO_SPEND_IN_LOW_POWER_MODE);
        Error_Handler();
    }

    Error_LED_De_Init();

    Configure_For_Low_Power();

    while (1) {
        PWR_Enter_Low_Power_Mode();
    }
}

/**
 * Configure system clock and oscillators.
 * Values used here were derived from CubeMX clock config to achieve 80MHz for
 * system clock
 *
 * @return  True if the initialization is successful. False otherwise.
 */
static Boolean SystemClockConfig(void) {
    RCC_OscInitTypeDef osc_init = { 0 };
    RCC_ClkInitTypeDef clk_init = { 0 };
    const uint32_t flash_latency = FLASH_LATENCY_4; // Table 9 in reference manual

    // Use LSE for standby clock and MSI for system + peripheral clock
    osc_init.OscillatorType = (RCC_OSCILLATORTYPE_LSE | RCC_OSCILLATORTYPE_MSI);

    // Configure MSI for 4MHz
    osc_init.MSIState = RCC_MSI_ON;
    osc_init.MSICalibrationValue = RCC_MSICALIBRATION_DEFAULT;
    osc_init.MSIClockRange = RCC_MSIRANGE_6;

    // Configure LSE for clock in standby mode
    osc_init.LSEState = RCC_LSE_ON;

    // Configure PLL to generate 80MHz clock
    osc_init.PLL.PLLState = RCC_PLL_ON;
    osc_init.PLL.PLLSource = RCC_PLLSOURCE_MSI;
    osc_init.PLL.PLLM = 1;
    osc_init.PLL.PLLN = 40;
    osc_init.PLL.PLLR = RCC_PLLR_DIV2;

    if (HAL_RCC_OscConfig(&osc_init) != HAL_OK) {
        return FALSE;
    }

    // Configure PLL as the clock for system + peripherals
    clk_init.ClockType = (RCC_CLOCKTYPE_SYSCLK | RCC_CLOCKTYPE_HCLK |
    RCC_CLOCKTYPE_PCLK1 | RCC_CLOCKTYPE_PCLK2);
    clk_init.SYSCLKSource = RCC_SYSCLKSOURCE_PLLCLK;
    clk_init.AHBCLKDivider = RCC_SYSCLK_DIV1;
    clk_init.APB1CLKDivider = RCC_HCLK_DIV1;
    clk_init.APB2CLKDivider = RCC_HCLK_DIV1;
    if (HAL_RCC_ClockConfig(&clk_init, flash_latency) != HAL_OK) {
        return FALSE;
    }

    // Update systick config according to the new clock source
    if (HAL_SYSTICK_Config(HAL_RCC_GetHCLKFreq() / 1000) != HAL_OK) {
        return FALSE;
    }
    HAL_SYSTICK_CLKSourceConfig(SYSTICK_CLKSOURCE_HCLK);

    return TRUE;
}

/**
 * Error handler to use until system clock and error LED are not initialized
 */
static void Early_Stage_Error_Handler(void) {
    while (1)
        ;
}

/**
 * Error handler to use after system clock and error LED are initialized
 */
void Error_Handler(void) {
    Error_LED_Indicate_Error();
    while (1)
        ;
}

/**
 * Configure the MCU to consume the least amount of current when sleeping, in
 * order to extend battery life
 */
static void Configure_For_Low_Power(void) {
    // Put *UNUSED* GPIO Pins in Analog mode and disable clock to
    // them to save power: Application note 4899, Section 7
    // Section 8.5.1 mentions that after reset the GPIO pins are put in Analog
    // mode. So we don't need to change that

    // Disable clock for GPIO peripherals
    __HAL_RCC_GPIOA_CLK_DISABLE();
    __HAL_RCC_GPIOB_CLK_DISABLE();
}

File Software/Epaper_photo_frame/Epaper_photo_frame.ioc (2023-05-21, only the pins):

Mcu.UserName=STM32L431CBTx
PA1.GPIO_Label=EPD_SPI_SCK
PA1.Signal=SPI1_SCK
PA11.GPIO_Label=SDC_PWR
PA11.Signal=GPIO_Output
PA3.GPIO_Label=EPD_RESET
PA3.Signal=GPIO_Output
PA5.GPIO_Label=EPD_BUSY
PA5.Signal=GPIO_Output
PA7.GPIO_Label=EPD_SPI_MOSI
PA7.Signal=SPI1_MOSI
PA9.GPIO_Label=SDC_SPI_NSS
PA9.Signal=GPIO_Output
PB1.GPIO_Label=EPD_DC
PB1.Signal=GPIO_Output
PB10.GPIO_Label=EPD_SPI_NSS
PB10.Signal=GPIO_Output
PB13.GPIO_Label=SDC_SPI_SCK
PB13.Signal=SPI2_SCK
PB14.GPIO_Label=SDC_SPI_MISO
PB14.Signal=SPI2_MISO
PB15.GPIO_Label=SDC_SPI_MOSI
PB15.Signal=SPI2_MOSI
PB5.GPIO_Label=LED_ERR
PB5.Signal=GPIO_Output
PB6.GPIO_Label=LED_BUSY
PB6.Signal=GPIO_Output
PB7.GPIO_Label=PWR_GOOD
PB7.Signal=GPIO_Input

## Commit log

2022-12-30 Add high side load switch to power off SD card when MCU sleeps
    Add code to control GPIO pin which enables/disables power to SD card
    Change sequence for SD card init and de-init code so that it is powered
    on only for as long as required
    Update README with new observations
2023-01-17 Initial commit for PCB design - Schematics
    [debug_connector.kicad_sch, display_adapter.kicad_sch, epaper_photo_frame.kicad_pcb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]
2023-01-17 Added footprint for components in Schematics. Updated LED resistors
    [debug_connector.kicad_sch, display_adapter.kicad_sch, epaper_photo_frame.kicad_pcb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]
2023-02-08 Added preliminary PCL layout
    [display_adapter.kicad_sch, epaper_photo_frame.kicad_pcb, epaper_photo_frame.kicad_sch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]
2023-02-27 Revision 1 of the board that was manufactured
    [debug_connector.kicad_sch, display_adapter.kicad_sch, epaper_photo_frame.kicad_pcb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]
2023-05-21 Fix NPN BJT Base and emitter pin swap. Attach BS0 to GND to select 4 pin SPI mode for Epaper display. Use 2 side FPC connector
    [display_adapter.kicad_sch, epaper_photo_frame.kicad_pcb]
2023-05-21 Create directories to add PCB and software. Modify code running on Development board to run on PCB
    [debug_connector.kicad_sch, display_adapter.kicad_sch, epaper_photo_frame.kicad_pcb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]
2023-05-21 Add schematic for circuit and Gerber files for manufacturing PCB
    [epaper_photo_frame-B_Cu.gbr, epaper_photo_frame-B_Mask.gbr, epaper_photo_frame-B_Paste.gbr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]
2023-07-29 Add 3d models for PCB and its components
2023-07-29 Add 3d printed files for enclosure. Add BOM and videos to help with assembly
    [FrontCover_oriented.stl, back_cover.stl, bom.csv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]
